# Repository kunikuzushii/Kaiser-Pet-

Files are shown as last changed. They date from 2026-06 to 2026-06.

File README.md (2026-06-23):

# Kaiser Pet 
tamagotchi project for fallout summer 2026
created by Youna Son (≧∇≦)ﾉ

ONSHAPE LINK:

https://cad.onshape.com/documents/d6c669abeeb3d7413e8d21f8/w/bde522f027b95c0c69872acb/e/c43f71f52c280984713279bd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

_________



# What is a Kaiser Pet? 

My custom themed tamagotchi has:
- RBG Screen
- Higher quality pixel art
- Photoresister (light sensor)

and most importantly... ITS FREAKING MICHAEL KAISER!!!

You take care of Kaiser from Blue Lock (animanga) like a standard tamagotchi. For example, you monitor their health, energy, and hunger levels and take care of them accordingly.

Hunger bar too low? 
Feed them!

Energy bar high?
Play with them!

Except it's better because you take care of the goat

______

# Why It Was Made? o((>ω< ))o

I cannot put into words for my love this character. The explanation behind it would likely take up 5 pages on a size 12, Times New Romans, single spaced google document for me to even START talking about it.
ps... you guys should see my embarassing pinterest page of over 300+ pins of Kaiser that made the zine process super easy (Sorry, I'm a pinterest warrior) AND my cosplays

Jokes aside, the main purpose is obviously: ENTERTAINMENT!

With the hype of the World Cup / FIFA, I think taking care of a character based off a soccer animanga would be super cool and fun.
Additionally, I really do want to use this regularly in my life, I love this character to the point where the whole event of fallout might've been an excuse to me building a super sick hardware project that suspiciously caters to my interests

# Pictures (☆▽☆)

CAD image:


Render images (in the zine):





PCB:





Sneak peek of my pixel art!:



______
## Bill of Materials

**Total Cost: $30.03**

| Name | Qty | Unit | Price (USD) | Total (USD) | MOQ | MOQ Price | Source |
| :--- | :---: | :---: | ---: | ---: | :---: | ---: | :--- |
| XIAO ESP32C3 | 1 | pcs | $4.99 | $4.99 | 1 | $4.99 | [Order](https://www.seeedstudio.com/Seeed-XIAO-ESP32C3-p-5431.html) |
| XHXDZ 1207-P6.5MM Buzzer | 1 | pcs | $0.50 | $5.03 | 10 | $5.03 | [Order](https://www.aliexpress.us/item/3256810135642750.html) |
| HS180S10B Screen | 1 | pcs | $3.21 | $3.21 | 1 | $3.21 | [Order](https://www.lcsc.com/product-detail/C5329585.html) |
| RC0805FR-0710KL Resistor | 1 | pcs | $0.10 | $0.10 | 1 | $0.10 | [Order](https://www.digikey.com/en/products/detail/yageo/RC0805FR-0710KL/727535) |
| GL12528 LDR | 1 | pcs | $0.31 | $1.56 | 5 | $1.56 | [Order](https://www.lcsc.com/product-detail/C559386.html) |
| M20-9990246 Connector | 1 | pcs | $0.10 | $0.10 | 1 | $0.10 | [Order](https://www.digikey.com/en/products/detail/harwin-inc/M20-9990246/3728226) |
| TSC016A04518A Tactile Switch | 3 | pcs | $0.01 | $0.54 | 50 | $0.54 | [Order](https://www.lcsc.com/product-detail/C2888493.html) |
| Battery | 1 | pcs | $6.20 | $6.20 | 1 | $6.20 | [Order](https://www.aliexpress.us/item/3256808658204287.html) |
| PCB | 1 | pcs | $0.40 | $2.00 | 5 | $2.00 | [Order](https://jlcpcb.com) |
| PLA Housing | 1 | pcs | - | - | - | - | Self-Print / Local |
| M3 x 10mm Socket Cap Head Screws | 3 | pcs | $0.47 | $1.88 | 4 | $1.88 | [Order](https://accu-components.com/us/metric-cap-head-screws/16004-SSCF-M3-10-12-9) |
| M3 x 5mm Socket Cap Head Screws | 5 | pcs | $0.31 | $1.86 | 6 | $1.86 | [Order](https://accu-components.com/us/metric-cap-head-screws/16001-SSCF-M3-5-12-9) |
| TS-107-T-AA Connector | 2 | pcs | $1.28 | $2.56 | 1 | $1.28 | [Order](https://www.digikey.com/en/products/detail/samtec-inc/TS-107-T-AA/10218878) |

Total Cost (USD) is the REAL price required before shipping fees
____

# BUILD & ASSEMBLY
___
# Required Tools
___
1) Solder
2) Sldering iron
3) Tweezers
4) 3D Printer
5) Screwdriver for M3 5mm & M3 10mm Screws
6) Electronic device to connect to tamagotchi through USB port

# Assembly Directions
____
1) Solder the Seeed Studio XIAO ESP32-C3, OLED display header connections, joystick module header connections, tact switches, battery connector, and all remaining through-hole and surface-mount components onto the PCB according to the schematic and PCB layout.
2) Check for incomplete connections.
3) Press the buttons down until they fit. 
4) Mount the joystick module to the PCB using 2× M2 × 5 mm screws, M2 standoffs, and M2 hex nuts. Make sure the joystick remains centered and perpendicular to the PCB.
5) Route the battery leads to cable path and place the lipo battery into the battery compartment right below the pcb or just look under.
6) Solder/connect the battery to the PCB battery connector. Check for polarity!
7) Align PCB assembly with the mounting posts inside the bottom case and SLOWLY put it into place. 
8) Secure the PCB to the bottom case using 3× M3 mounting screws, tightening them evenly. Please focus on tightening them properly before it just falls out. (haha, falls out like. fallout. haha)
9) Verify that it aligns again. This is super important!
10) Position the top case onto the bottom case.
11) Fasten the enclosure halves together using the specified M1.6 screws, tightening each screw gradually in an alternating pattern to ensure even clamping.
12) Install all the software libraries in Arduino.
13) Connect the XIAO ESP32-C3 to a computer using a USB-C cable and select the correct board and COM port within the Arduino IDE.
14) Compile firmware! Check everything including error messages (shouldn't be any).
15) Upload the firmware to the ESP32-C3, make sure you get the completion message.
16) Turn it on or off to check if it connects properly especially without USB connection.
17) Test the OLED if it renders everything properly.
18) Test all button inputs, you can manipulate the button functions off the firmware if you really want to.
19) Confirm everything else: charging, functioning, missing pixels, etc.

Congrats! I hope someone can actually enjoy this and build it for themselves!

# CREDITS:
- ONSHAPE (for CAD)
- KiCAD (all hardware / PCB stuff)
- Fallout

LIBRARIES CREDITS
## Dependencies
You need these libraries (add to Arduino libraries managers)
* **Adafruit GFX Library** (by Adafruit)
* **Adafruit ST7735 and ST7789 Library** (by Adafruit)
* **SPI** (Built-in to Arduino IDE)

# PIXEL ART AND ZINE CREDITS
REFERENCES AND INSPIRATION (Pinterest!) :

- https://www.pinterest.com/pin/168322104817334436/
- https://www.pinterest.com/pin/888123989041302114/
- https://www.pinterest.com/pin/114560384269168373/
- https://www.pinterest.com/pin/888123989035366728/
- https://www.pinterest.com/pin/888123989035906915/
- https://pin.it/148EMhVAn
- https://share.google/kxDoDrVdniUi0Naia
- https://pin.it/6CnxexgHx

and obviously, kudos to Muneyuki Kaneshiro for making my favorite character and Yusuke Nomura for bringing him to life by drawing him.

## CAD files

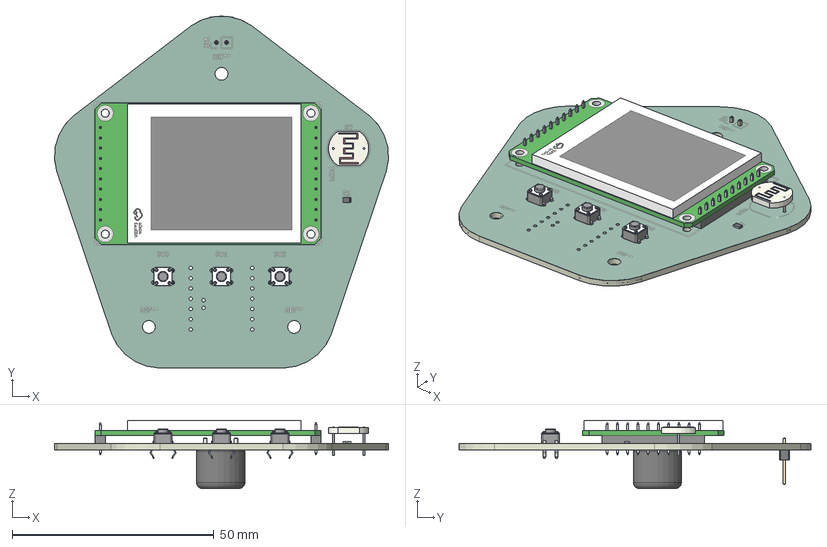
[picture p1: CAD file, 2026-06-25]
PCB Files/pcb.step
82.8 x 87.3 x 16.9 mm
tamagotchi_copper x 31
tamagotchi_silkscreen x 88
tamagotchi_PCB
PinHeader_1x02_P254mm_Vertical
tamagotchi_via x 3
tamagotchi_soldermask x 2
Buzzer_12x95RM76
R_LDR_10x8.5mm_P7.6mm_Vertical x 2
LCD-TH_L56.0-W35.0-P2.54_HS180S10B
R_0805_2012Metric

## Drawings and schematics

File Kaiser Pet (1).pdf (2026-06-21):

# kAiser pet

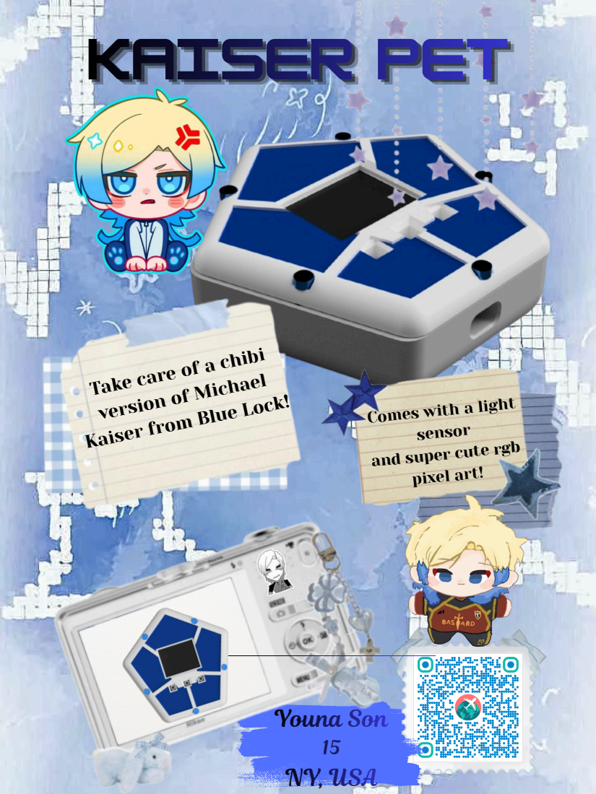
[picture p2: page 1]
Youna Son 15 NY, USA; sensor; pixel art!

Take care of a chibi

version of Michael

Kaiser from Blue Lock!

Comes with a light

and super cute rgb

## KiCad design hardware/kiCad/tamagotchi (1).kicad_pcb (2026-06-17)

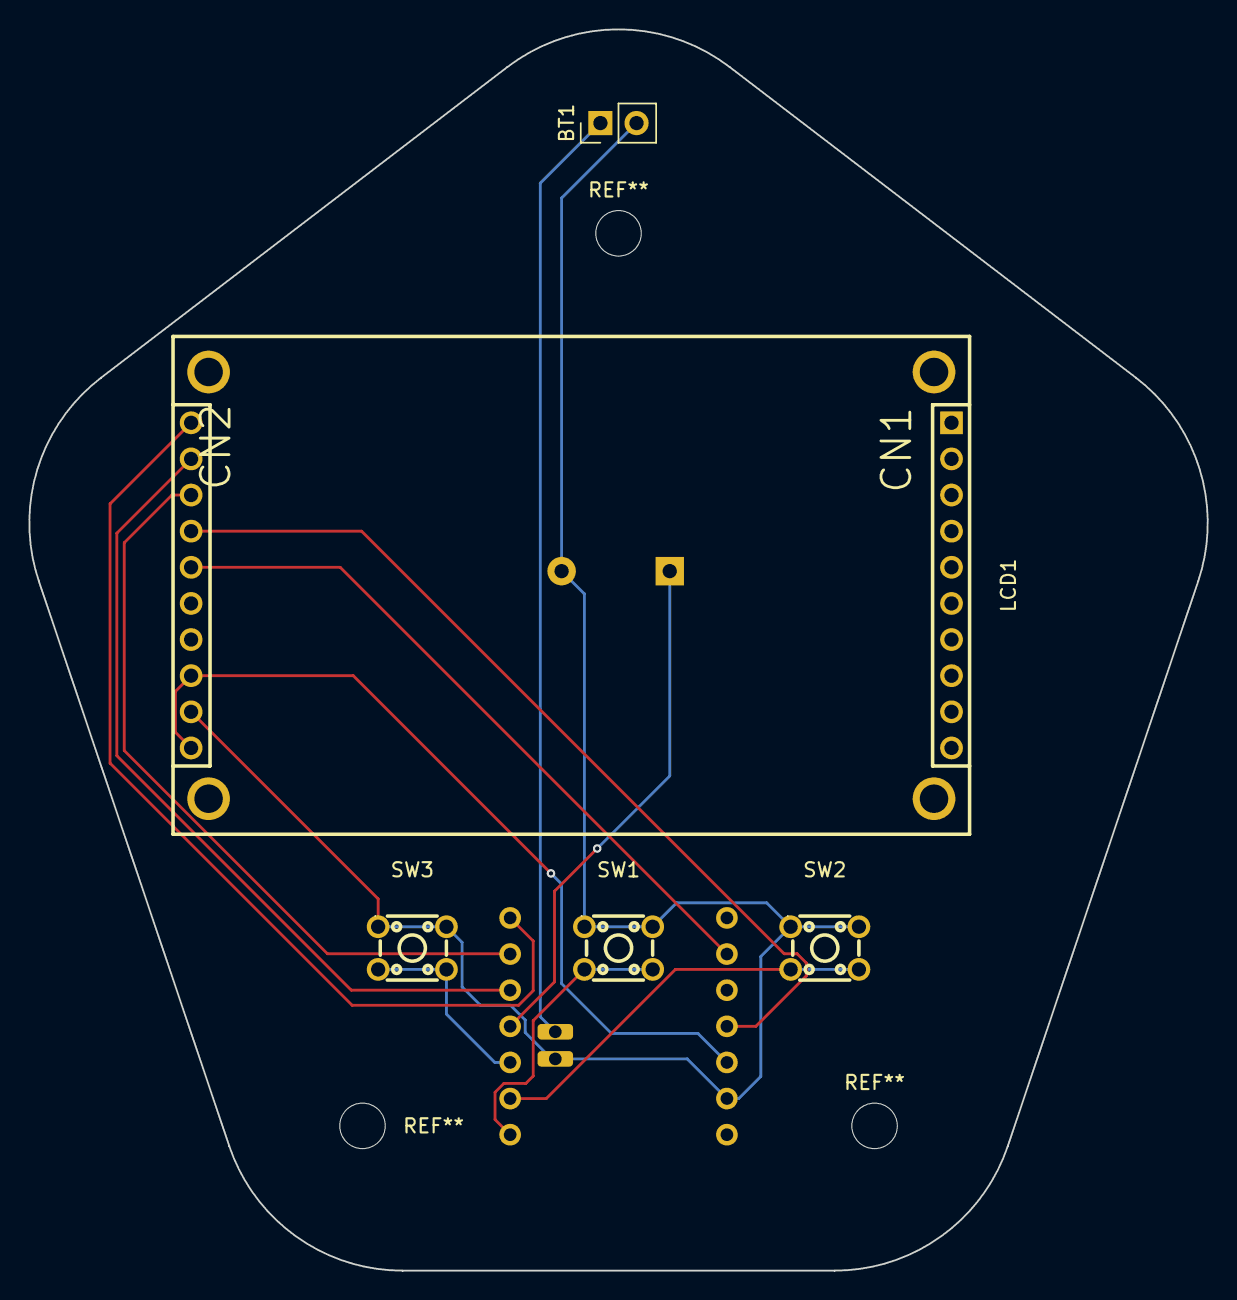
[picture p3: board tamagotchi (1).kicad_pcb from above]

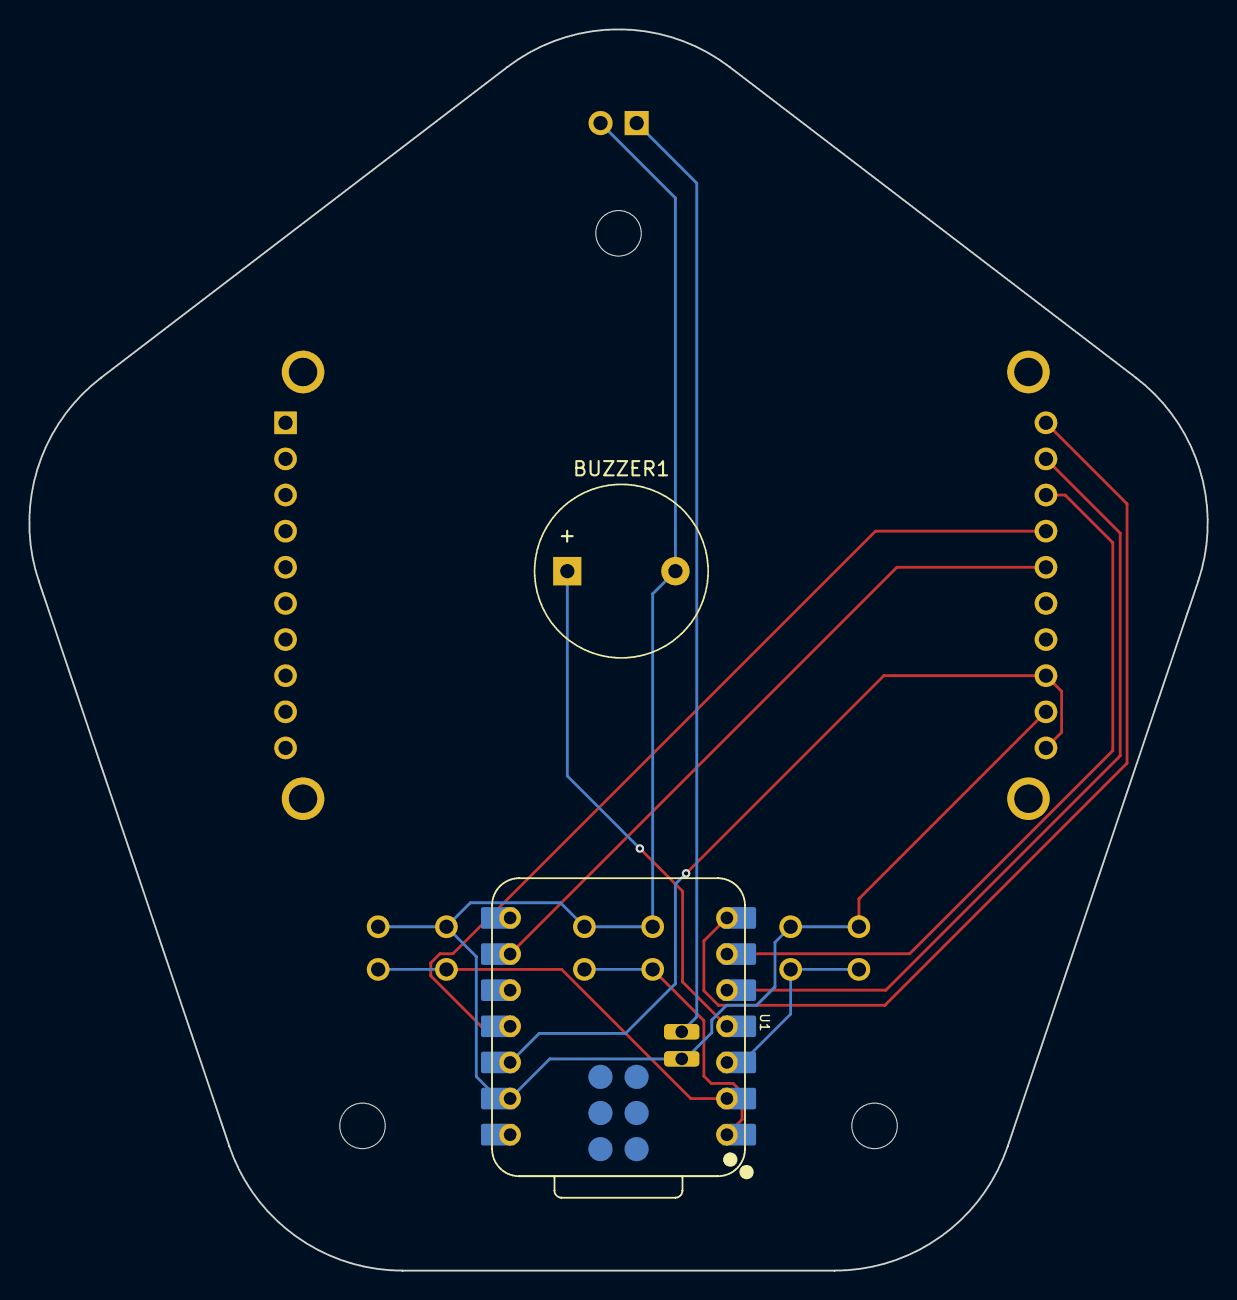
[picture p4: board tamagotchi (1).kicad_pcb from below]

Board: 2 copper layers, 82.8 x 87.3 mm, 7 parts (2 on the bottom side), 12 nets.

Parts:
BT1: Battery_Cell; PinHeader_1x02_P2.54mm_Vertical
BUZZER1: 1207-P6.5MM; Buzzer_12x9.5RM7.6
LCD1: HS180S10B; LCD-TH_L56.0-W35.0-P2.54_HS180S10B
SW1, SW2, SW3: SW_Push; SW-TH_4P-L4.5-W4.5-P3.00-LS4.8
U1: XIAO-ESP32-C3-SMD; XIAO-ESP32-C3-DIP-SMD

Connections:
+3V3: LCD1.11, LCD1.13, U1.12 (3V3)
+BATT: BT1.1 (+), U1.15
/CS1: LCD1.20, U1.7 (GPIO21_D6_TX)
/DC: LCD1.18, U1.6 (GPIO7_D5_SCL)
/RES: LCD1.19, U1.5 (GPIO6_D4_SDA)
GND: BT1.2 (-), BUZZER1.2 (-), LCD1.12, SW1.1, SW2.1, SW3.1, U1.13 (GND), U1.16
unnamed: BUZZER1.1 (+), U1.4 (GPIO5_A3_D3)
unnamed: SW1.2, U1.1 (GPIO2_A0_D0)
unnamed: SW2.2, U1.2 (GPIO3_A1_D1)
unnamed: SW3.2, U1.3 (GPIO4_A2_D2)
unnamed: LCD1.16, U1.9 (GPIO8_D8_SCK)
unnamed: LCD1.17, U1.11 (GPIO10_D10_MOSI)

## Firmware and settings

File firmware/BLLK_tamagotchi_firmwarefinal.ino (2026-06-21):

#include <SPI.h>
#include <Adafruit_GFX.h>
#include <Adafruit_ST7735.h>

#include "kaiser_sprites.h"

// Buttons
#define BTN_LEFT   2
#define BTN_MIDDLE 3
#define BTN_RIGHT  4

// Sensors
#define LIGHT_PIN 20
#define LIGHT_DARK_STATE LOW

// Audio
#define BUZZER_PIN 5

// TFT
#define TFT_CS   21
#define TFT_DC   7
#define TFT_RST  6
#define TFT_SCLK 8
#define TFT_MOSI 10

// Backlight
#define TFT_BLK 9

enum Pose {
  POSE_NORMAL,
  POSE_EATING,
  POSE_PLAYING,
  POSE_SLEEPING,
  POSE_RESTING
};

void updateLightSensor();
void updatePet();
void checkButtons();
void handleScreenLogic();
void drawMainScreen();
void drawStats();
void drawStatBar(int x, int y, const char *label, int value, uint16_t color);
void drawCurrentSprite();
void showPose(Pose pose, unsigned long durationMs);
int clampStat(int value);
void beep(unsigned int frequency, unsigned long durationMs);

unsigned long nextIdlePose = 0;

#define SCREEN_WIDTH  160
#define SCREEN_HEIGHT 128

Adafruit_ST7735 tft = Adafruit_ST7735(TFT_CS, TFT_DC, TFT_MOSI, TFT_SCLK, TFT_RST);

struct Pet {
  int hunger;        // 0 to 100 (0 = starving, 100 = full)
  int happiness;     // 0 to 100 (0 = miserable, 100 = delighted)
  int energy;        // 0 to 100 (0 = exhausted, 100 = fully rested)
  int health;        // 0 to 100 (0 = sick, 100 = healthy)
  unsigned long age; // total seconds the pet has been alive
};

Pet pet;

enum Screen {
  SCREEN_MAIN,
  SCREEN_FEED,
  SCREEN_PLAY,
  SCREEN_SLEEP
};

Screen currentScreen = SCREEN_MAIN;
Pose currentPose = POSE_NORMAL;

unsigned long lastUpdate = 0;
unsigned long lastButtonPress = 0;
unsigned long poseUntil = 0;
unsigned long lastDraw = 0;
bool roomIsDark = false;

const uint16_t COLOR_BG = ST77XX_WHITE;
const uint16_t COLOR_TEXT = ST77XX_BLACK;
const uint16_t COLOR_BAR_BG = 0xDEFB; // light gray
const uint16_t COLOR_HUNGER = 0xFD20; // orange
const uint16_t COLOR_ENERGY = ST77XX_BLUE;
const uint16_t COLOR_HAPPY = ST77XX_GREEN;
const uint16_t COLOR_HEALTH = ST77XX_RED;

const int SPRITE_X = 8;
const int SPRITE_Y = 24;

void setup() {
  randomSeed(analogRead(0));

  pinMode(BTN_LEFT, INPUT_PULLUP);
  pinMode(BTN_MIDDLE, INPUT_PULLUP);
  pinMode(BTN_RIGHT, INPUT_PULLUP);
  if (LIGHT_PIN >= 0) {
    pinMode(LIGHT_PIN, INPUT);
  }
  if (BUZZER_PIN >= 0) {
    pinMode(BUZZER_PIN, OUTPUT);
  }
  pinMode(TFT_BLK, OUTPUT);
  digitalWrite(TFT_BLK, HIGH);

  tft.initR(INITR_BLACKTAB);
  tft.setRotation(1);
  tft.fillScreen(COLOR_BG);
  tft.setTextWrap(false);

  tft.fillScreen(ST77XX_WHITE);
  tft.setTextColor(ST77XX_BLACK);
  tft.setTextSize(2);
  tft.setCursor(25, 30);
  tft.print("KAISER");

  tft.setTextSize(1);
  tft.setCursor(20, 60);
  tft.print("Blue Lock Pet");

  delay(2000);

  pet.hunger = 80;
  pet.happiness = 80;
  pet.energy = 80;
  pet.health = 100;
  pet.age = 0;
}

void loop() {
  updateLightSensor();
  updatePet();
  checkButtons();
  handleScreenLogic();
  drawMainScreen();
}

void updateLightSensor() {
  if (LIGHT_PIN < 0) {
    roomIsDark = false;
    return;
  }

  roomIsDark = digitalRead(LIGHT_PIN) == LIGHT_DARK_STATE;
}

void updatePet() {
  if (millis() - lastUpdate > 60000) {
    pet.hunger--;
    pet.happiness--;
    pet.energy--;

    if (
      pet.hunger > 60 &&
      pet.happiness > 60 &&
      pet.energy > 60
    ) {
      pet.health++;
    }
    else if (
      pet.hunger < 20 ||
      pet.happiness < 20 ||
      pet.energy < 20
    ) {
      pet.health--;
    }
    if (roomIsDark) {
      pet.energy++;
    }

    pet.hunger = clampStat(pet.hunger);
    pet.happiness = clampStat(pet.happiness);
    pet.energy = clampStat(pet.energy);
    pet.health = clampStat(pet.health);

    pet.age += 5;
    lastUpdate = millis();
  }
}

void checkButtons() {
  if (millis() - lastButtonPress < 200) return;

  if (digitalRead(BTN_LEFT) == LOW) {
    currentScreen = SCREEN_FEED;
    beep(1000, 50);
    lastButtonPress = millis();
  } else if (digitalRead(BTN_MIDDLE) == LOW) {
    currentScreen = SCREEN_PLAY;
    beep(1200, 50);
    lastButtonPress = millis();
  } else if (digitalRead(BTN_RIGHT) == LOW) {
    currentScreen = SCREEN_SLEEP;
    beep(800, 50);
    lastButtonPress = millis();
  }
}

void handleScreenLogic() {
  switch (currentScreen) {
    case SCREEN_FEED:
      pet.hunger += 10;
      pet.health += 2;
      pet.hunger = clampStat(pet.hunger);
      pet.health = clampStat(pet.health);
      showPose(POSE_EATING, 900);
      currentScreen = SCREEN_MAIN;
      break;

    case SCREEN_PLAY:
      pet.happiness += 10;
      pet.energy -= 5;
      pet.happiness = clampStat(pet.happiness);
      pet.energy = clampStat(pet.energy);
      showPose(POSE_PLAYING, 900);
      currentScreen = SCREEN_MAIN;
      break;

    case SCREEN_SLEEP:
      if (
        !roomIsDark &&
        millis() > poseUntil &&
        millis() > nextIdlePose
      ) {
        currentPose = random(0, 2) ? POSE_NORMAL : POSE_RESTING;
        poseUntil = millis() + 1200;
        nextIdlePose = millis() + random(4000, 9000);
      }
      pet.energy += 15;
      pet.health += 3;
      pet.energy = clampStat(pet.energy);
      pet.health = clampStat(pet.health);
      showPose(POSE_SLEEPING, 1200);
      currentScreen = SCREEN_MAIN;
      break;

    case SCREEN_MAIN:
      break;
  }
}

void drawMainScreen() {
  if (millis() - lastDraw < 100) return;
  lastDraw = millis();

  tft.fillScreen(COLOR_BG);
  drawStats();
  drawCurrentSprite();
  tft.setCursor(86, 44);
  tft.setTextColor(COLOR_TEXT, COLOR_BG);
  tft.print("AGE ");
  tft.print(pet.age / 60);
  tft.print("m");
}

void drawStats() {
  drawStatBar(86, 2, "HUNGRY", pet.hunger, COLOR_HUNGER);
  drawStatBar(86, 12, "ENERGY", pet.energy, COLOR_ENERGY);
  drawStatBar(86, 22, "HAPPY", pet.happiness, COLOR_HAPPY);
  drawStatBar(86, 32, "HEALTH", pet.health, COLOR_HEALTH);
}

void drawStatBar(int x, int y, const char *label, int value, uint16_t color) {
  const int barX = x + 42;
  const int barY = y + 1;
  const int barW = 22;
  const int barH = 6;
  const int fillW = map(value, 0, 100, 0, barW);

  tft.setTextColor(COLOR_TEXT, COLOR_BG);
  tft.setTextSize(1);
  tft.setCursor(x, y);
  tft.print(label);

  tft.drawRect(barX, barY, barW, barH, COLOR_TEXT);
  tft.fillRect(barX + 1, barY + 1, barW - 2, barH - 2, COLOR_BAR_BG);
  int innerFillW = fillW - 2;
  if (innerFillW < 0) innerFillW = 0;
  tft.fillRect(barX + 1, barY + 1, innerFillW, barH - 2, color);
}

void drawCurrentSprite() {
  const uint16_t *sprite = KAISER_NORMAL;

  if (roomIsDark) {
    sprite = KAISER_SLEEP;
  } else if (millis() < poseUntil) {
    switch (currentPose) {
      case POSE_EATING:
        sprite = KAISER_EAT;
        break;
      case POSE_PLAYING:
        sprite = KAISER_PLAY;
        break;
      case POSE_SLEEPING:
        sprite = KAISER_SLEEP;
        break;
      case POSE_RESTING:
        sprite = KAISER_REST;
        break;
      case POSE_NORMAL:
        sprite = KAISER_NORMAL;
        break;
    }
  } else if (pet.health < 40 || pet.energy < 30) {
    sprite = KAISER_REST;
  }

  tft.drawRGBBitmap(SPRITE_X, SPRITE_Y, sprite, KAISER_SPRITE_WIDTH, KAISER_SPRITE_HEIGHT);
}

void showPose(Pose pose, unsigned long durationMs) {
  currentPose = pose;
  poseUntil = millis() + durationMs;
}

int clampStat(int value) {
  if (value < 0) return 0;
  if (value > 100) return 100;
  return value;
}

void beep(unsigned int frequency, unsigned long durationMs) {
  if (BUZZER_PIN >= 0) {
    tone(BUZZER_PIN, frequency, durationMs);
  }
}

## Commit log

2026-06-21 Revise README with project overview and assembly guide
    Updated the README.md to include project details, assembly instructions, and credits.
2026-06-22 Convert BOM file to CSV format
    Updated BOM format from markdown to CSV format.
    [bom.csv]
2026-06-23 Revise README for Kaiser Pet project
    Updated README.md to include project details, assembly instructions, and credits.
2026-06-23 bom formatting on readme fixed
2026-06-25 file name change
    [BOM.csv]
